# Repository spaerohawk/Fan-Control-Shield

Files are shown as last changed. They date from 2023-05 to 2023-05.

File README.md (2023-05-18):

# Fan-Control-Shield
 ## Design files for Fan Control Shield for Nucleo f4x9zi.
  
 Designed by Chris Dougherty while a graduate student at Caltech. 
 
 These design files are open-sourced pursuant to requirements set forth by NASA's Jet Propulsion Laboratory (JPL). A total of two research-grade fan array wind tunnels (FAWTs) were designed and developed to assist experimental campaign efforts to chamber-test Ingenuity (Mars Helicopter) in simulated Martian forward flight conditions. Given the multi-sourcedness of fan arrays, printed circuit breakout boards that neatly interface with multiples of fan units designed to meet electrical/thermal specifications and off-gassing chamber requirements were set forth in the scope of work.
 
- A 11x11x1 fan array was constructed in the basement of GALCIT using the Fan Control Shield found in release [v1.0.0](https://github.com/spaerohawk/Fan-Control-Shield/releases/tag/v1.0.0). 
* A 21x21x2 fan array[^1] was constructed in the 25-ft Space Simulator at JPL using the Fan Control Shield found in release [v1.1.0](https://github.com/spaerohawk/Fan-Control-Shield/releases/tag/v1.1.0).
  * Direct PDF access to the above noted paper can be found [here](https://rdcu.be/dcesM). 

[^1]: Veismann, M., Dougherty, C., Rabinovitch, J. et al. Low-density multi-fan wind tunnel design and testing for the Ingenuity Mars Helicopter. Exp Fluids 62, 193 (2021). https://doi.org/10.1007/s00348-021-03278-5

 Creative Commons Attribution/Share-Alike, all text above must be included in any redistribution. See license.txt for additional information.

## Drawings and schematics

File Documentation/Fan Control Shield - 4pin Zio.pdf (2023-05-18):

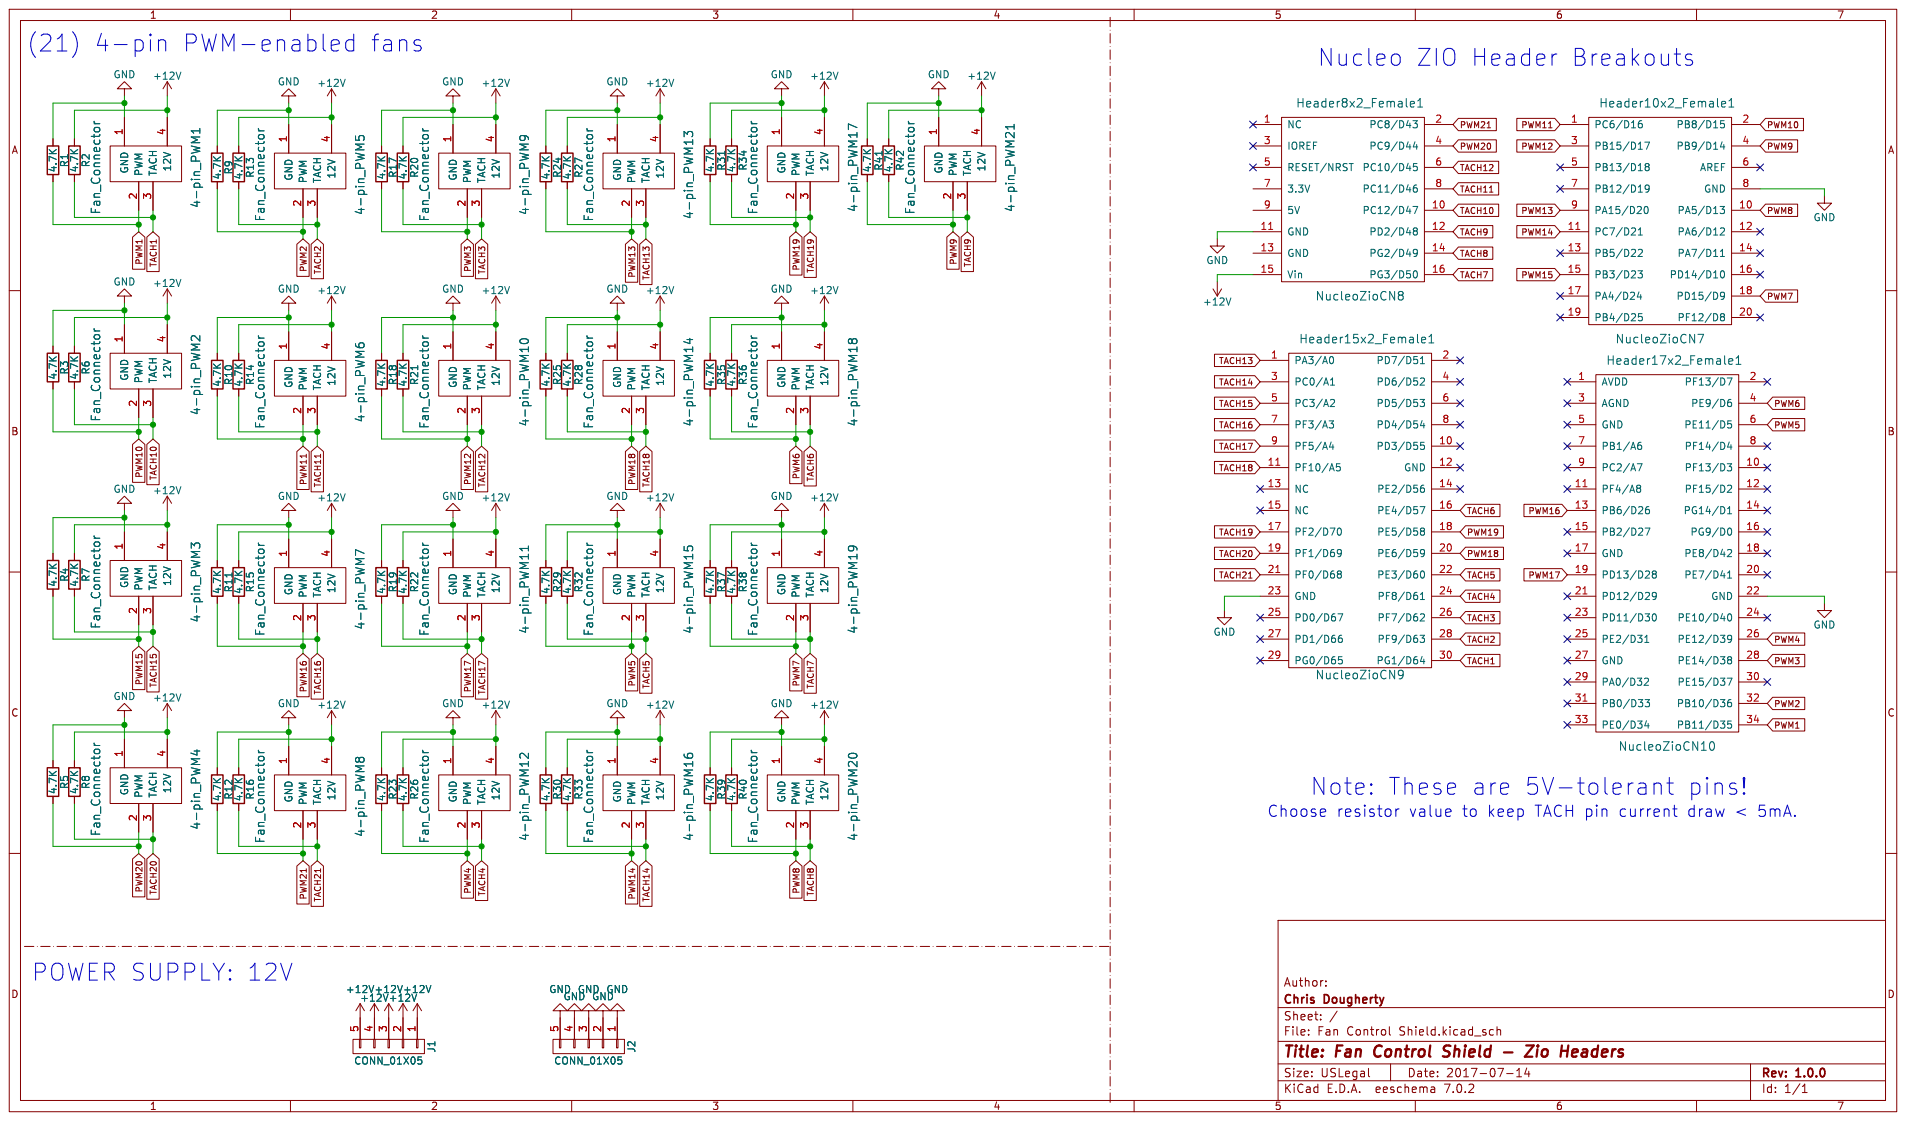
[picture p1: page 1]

Id: 1/1 Title: Fan Control Shield - Zio Headers

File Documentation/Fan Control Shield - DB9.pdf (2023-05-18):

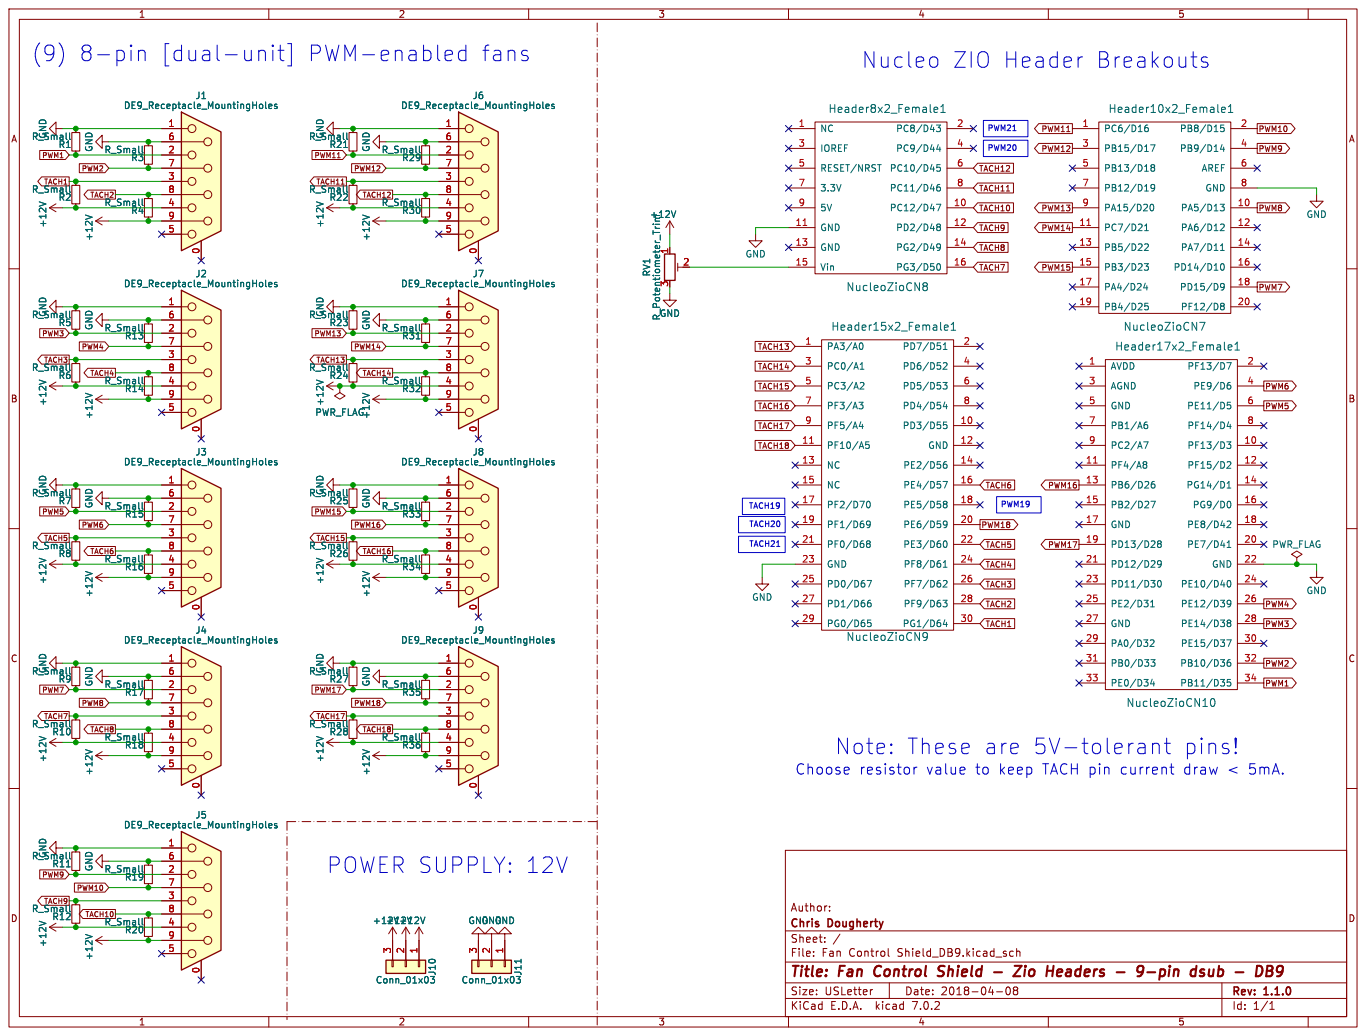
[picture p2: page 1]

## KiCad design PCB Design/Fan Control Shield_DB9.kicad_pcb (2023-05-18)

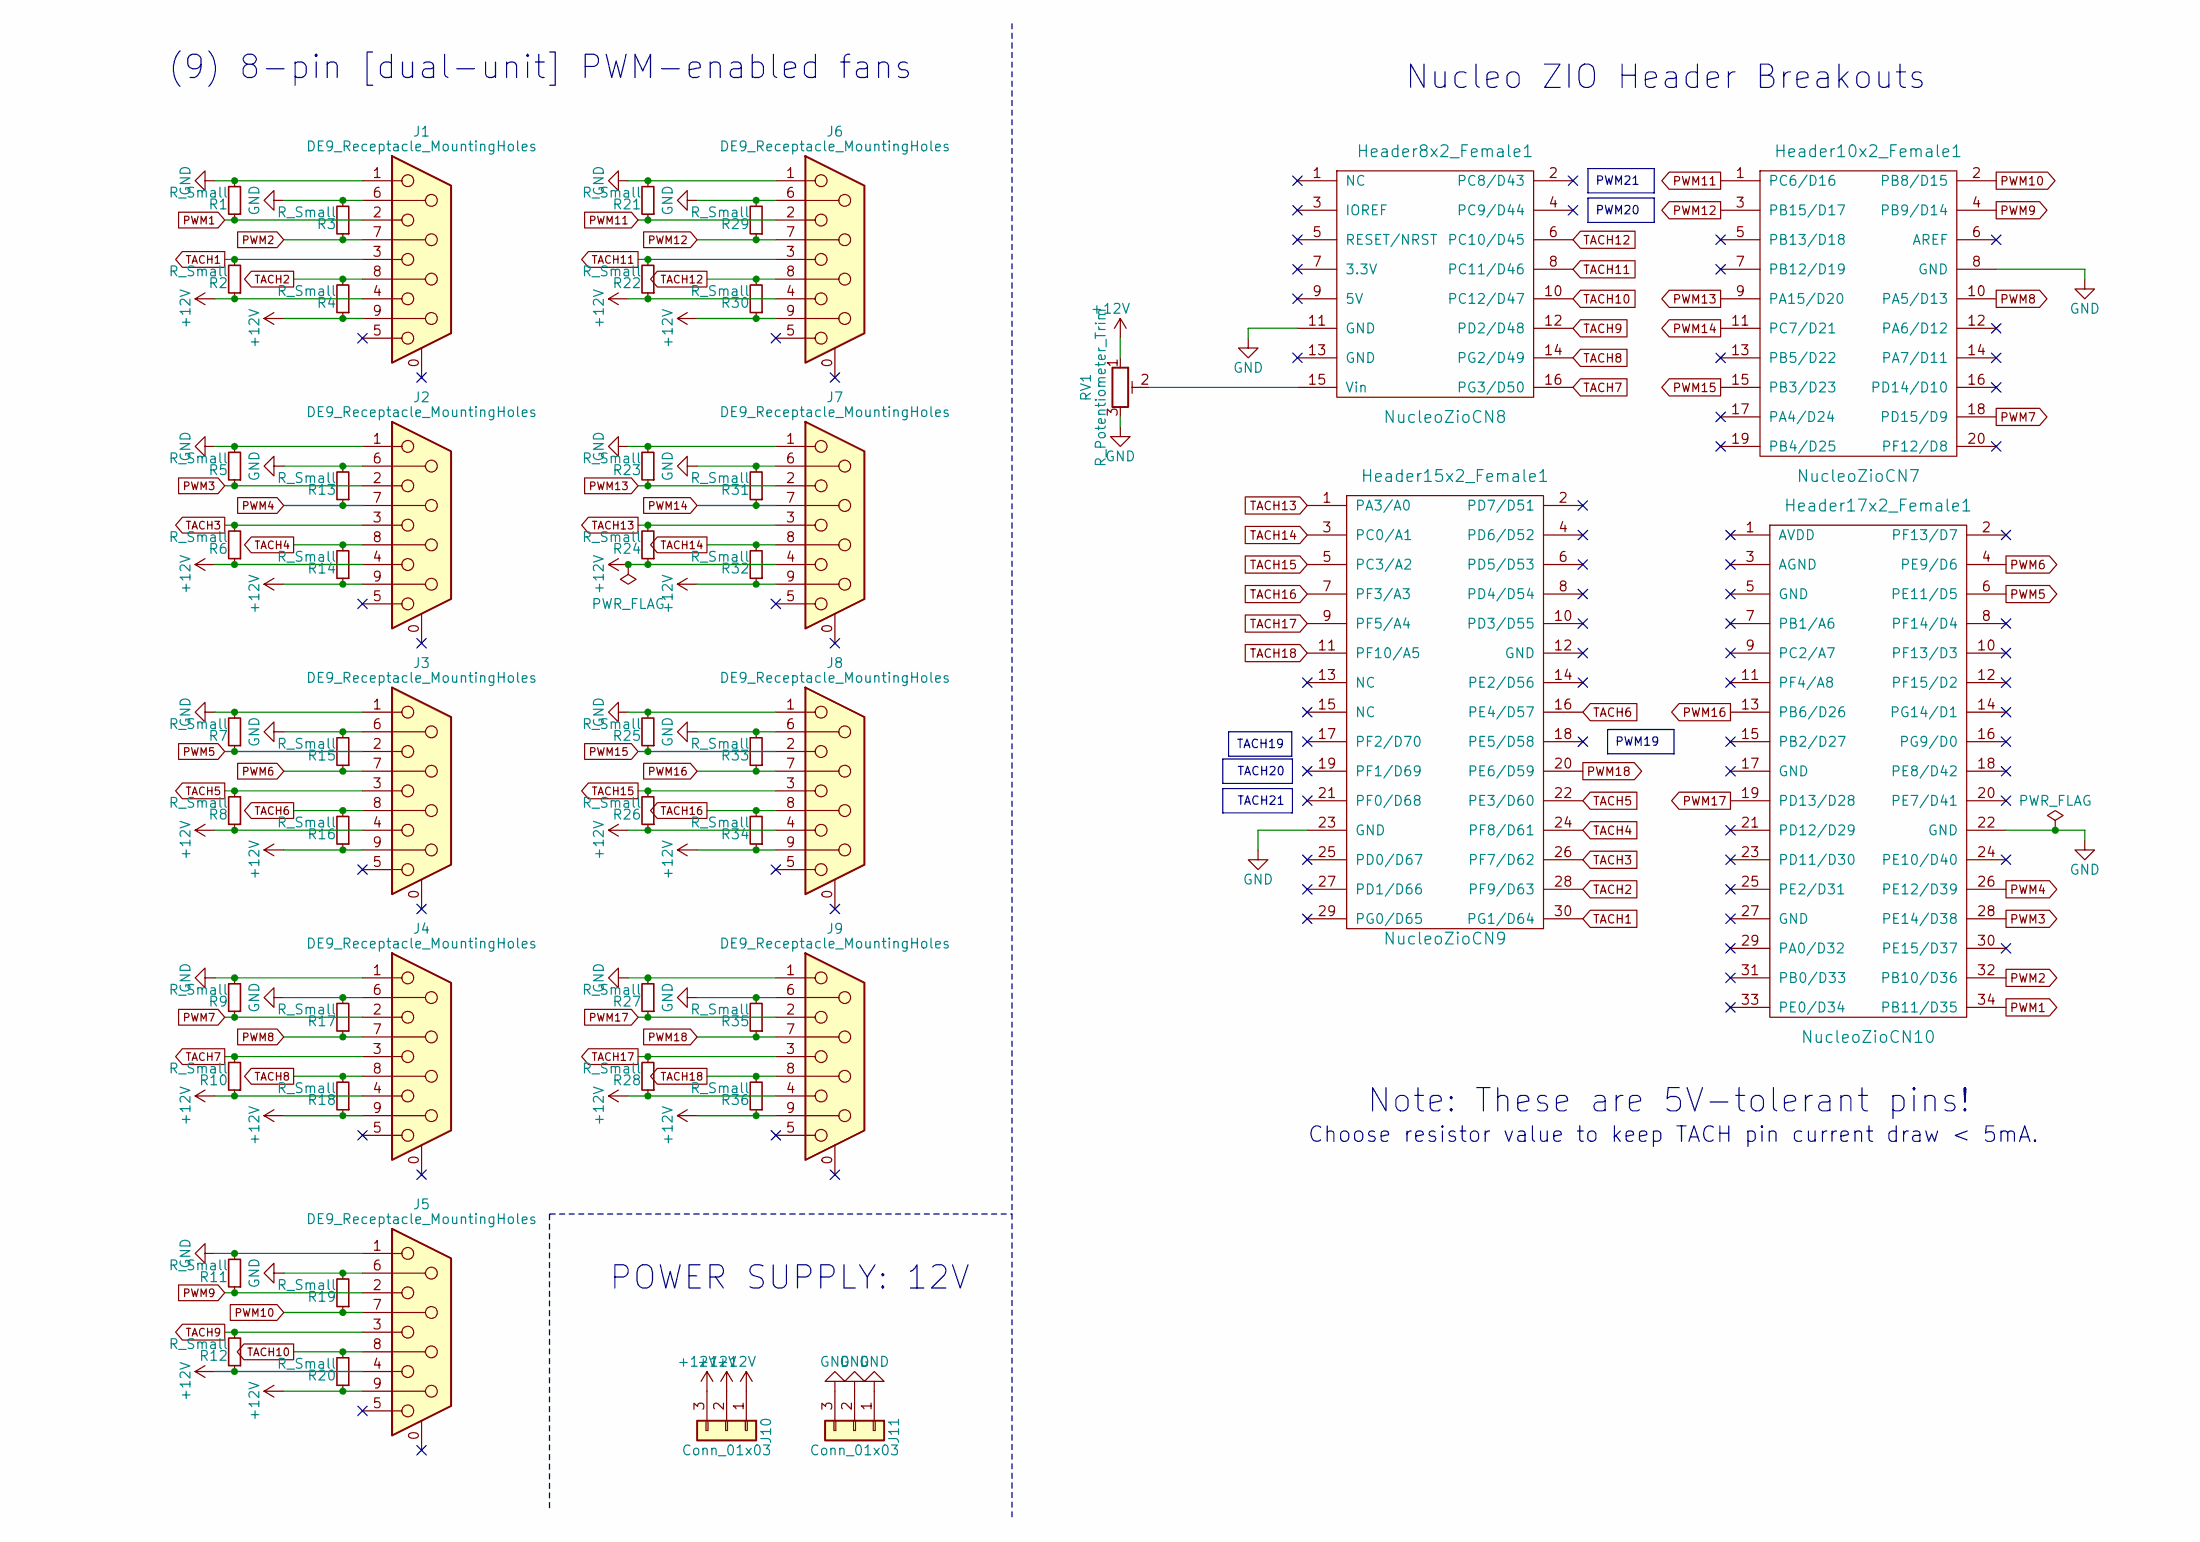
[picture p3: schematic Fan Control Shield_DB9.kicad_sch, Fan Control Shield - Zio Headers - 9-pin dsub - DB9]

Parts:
Header8x2_Female1: NucleoZioCN8; Socket_Strip_Straight_2x08_Pitch2.54mm
Header10x2_Female1: NucleoZioCN7; Socket_Strip_Straight_2x10_Pitch2.54mm
Header15x2_Female1: NucleoZioCN9; Socket_Strip_Straight_2x15_Pitch2.54mm
Header17x2_Female1: NucleoZioCN10; Socket_Strip_Straight_2x17_Pitch2.54mm
J1, J2, J3, J4, J5, J6, J7, J8, J9: DE9_Receptacle_MountingHoles; DSUB-9_Female_Vertical_P2.77x2.84mm_MountingHoles
J10, J11: Conn_01x03; CONN-TE-AMP3_P9.52
R1, R2, R3, R4, R5, R6, R7, R8, R9, R10, R11, R12, R13, R14, R15, R16, R17, R18, R19, R20, R21, R22, R23, R24, R25, R26, R27, R28, R29, R30, R31, R32, R33, R34, R35, R36: R_Small; R_1206_HandSoldering
RV1: R_Potentiometer_Trim; Potentiometer_Bourns_3266Y_Vertical

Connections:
+12V: J1.4, J1.9, J2.4, J2.9, J3.4, J3.9, J4.4, J4.9, J5.4, J5.9, J6.4, J6.9, J7.4, J7.9, J8.4, J8.9, J9.4, J9.9, J10.1, J10.2, J10.3, R2.1, R4.1, R6.1, R8.1, R10.1, R12.1, R14.1, R16.1, R18.1, R20.1, R22.1, R24.1, R26.1, R28.1, R30.1, R32.1, R34.1, R36.1, RV1.1
GND: Header8x2_Female1.11 (GND), Header10x2_Female1.8 (GND), Header15x2_Female1.23 (GND), Header17x2_Female1.22 (GND), J1.1, J1.6, J2.1, J2.6, J3.1, J3.6, J4.1, J4.6, J5.1, J5.6, J6.1, J6.6, J7.1, J7.6, J8.1, J8.6, J9.1, J9.6, J11.1, J11.2, J11.3, R1.2, R3.2, R5.2, R7.2, R9.2, R11.2, R13.2, R15.2, R17.2, R19.2, R21.2, R23.2, R25.2, R27.2, R29.2, R31.2, R33.2, R35.2, RV1.3; also elsewhere on the board
unnamed 2: Header8x2_Female1.15 (Vin), RV1.2; also elsewhere on the board
PWM1: Header17x2_Female1.34 (PB11/D35), J1.2, R1.1; also elsewhere on the board
PWM2: Header17x2_Female1.32 (PB10/D36), J1.7, R3.1; also elsewhere on the board
PWM3: Header17x2_Female1.28 (PE14/D38), J2.2, R5.1; also elsewhere on the board
PWM4: Header17x2_Female1.26 (PE12/D39), J2.7, R13.1; also elsewhere on the board
PWM5: Header17x2_Female1.6 (PE11/D5), J3.2, R7.1; also elsewhere on the board
PWM6: Header17x2_Female1.4 (PE9/D6), J3.7, R15.1; also elsewhere on the board
PWM7: Header10x2_Female1.18 (PD15/D9), J4.2, R9.1; also elsewhere on the board
PWM8: Header10x2_Female1.10 (PA5/D13), J4.7, R17.1; also elsewhere on the board
PWM9: Header10x2_Female1.4 (PB9/D14), J5.2, R11.1; also elsewhere on the board
PWM10: Header10x2_Female1.2 (PB8/D15), J5.7, R19.1; also elsewhere on the board
PWM11: Header10x2_Female1.1 (PC6/D16), J6.2, R21.1; also elsewhere on the board
PWM12: Header10x2_Female1.3 (PB15/D17), J6.7, R29.1; also elsewhere on the board
PWM13: Header10x2_Female1.9 (PA15/D20), J7.2, R23.1; also elsewhere on the board
PWM14: Header10x2_Female1.11 (PC7/D21), J7.7, R31.1; also elsewhere on the board
PWM15: Header10x2_Female1.15 (PB3/D23), J8.2, R25.1; also elsewhere on the board
PWM16: Header17x2_Female1.13 (PB6/D26), J8.7, R33.1; also elsewhere on the board
PWM17: Header17x2_Female1.19 (PD13/D28), J9.2, R27.1; also elsewhere on the board
PWM18: Header15x2_Female1.20 (PE6/D59), J9.7, R35.1; also elsewhere on the board
TACH1: Header15x2_Female1.30 (PG1/D64), J1.3, R2.2; also elsewhere on the board
TACH2: Header15x2_Female1.28 (PF9/D63), J1.8, R4.2; also elsewhere on the board
TACH3: Header15x2_Female1.26 (PF7/D62), J2.3, R6.2; also elsewhere on the board
TACH4: Header15x2_Female1.24 (PF8/D61), J2.8, R14.2; also elsewhere on the board
TACH5: Header15x2_Female1.22 (PE3/D60), J3.3, R8.2; also elsewhere on the board
TACH6: Header15x2_Female1.16 (PE4/D57), J3.8, R16.2; also elsewhere on the board
TACH7: Header8x2_Female1.16 (PG3/D50), J4.3, R10.2; also elsewhere on the board
TACH8: Header8x2_Female1.14 (PG2/D49), J4.8, R18.2; also elsewhere on the board
TACH9: Header8x2_Female1.12 (PD2/D48), J5.3, R12.2; also elsewhere on the board
TACH10: Header8x2_Female1.10 (PC12/D47), J5.8, R20.2; also elsewhere on the board
TACH11: Header8x2_Female1.8 (PC11/D46), J6.3, R22.2; also elsewhere on the board
TACH12: Header8x2_Female1.6 (PC10/D45), J6.8, R30.2; also elsewhere on the board
TACH13: Header15x2_Female1.1 (PA3/A0), J7.3, R24.2; also elsewhere on the board
TACH14: Header15x2_Female1.3 (PC0/A1), J7.8, R32.2; also elsewhere on the board
TACH15: Header15x2_Female1.5 (PC3/A2), J8.3, R26.2; also elsewhere on the board
TACH16: Header15x2_Female1.7 (PF3/A3), J8.8, R34.2; also elsewhere on the board
TACH17: Header15x2_Female1.9 (PF5/A4), J9.3, R28.2; also elsewhere on the board
TACH18: Header15x2_Female1.11 (PF10/A5), J9.8, R36.2; also elsewhere on the board

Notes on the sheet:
PWM20
PWM21
TACH19
PWM19
TACH21
TACH20
POWER SUPPLY: 12V
(9) 8-pin [dual-unit] PWM-enabled fans
Nucleo ZIO Header Breakouts
Choose resistor value to keep TACH pin current draw < 5mA.
Note: These are 5V-tolerant pins!

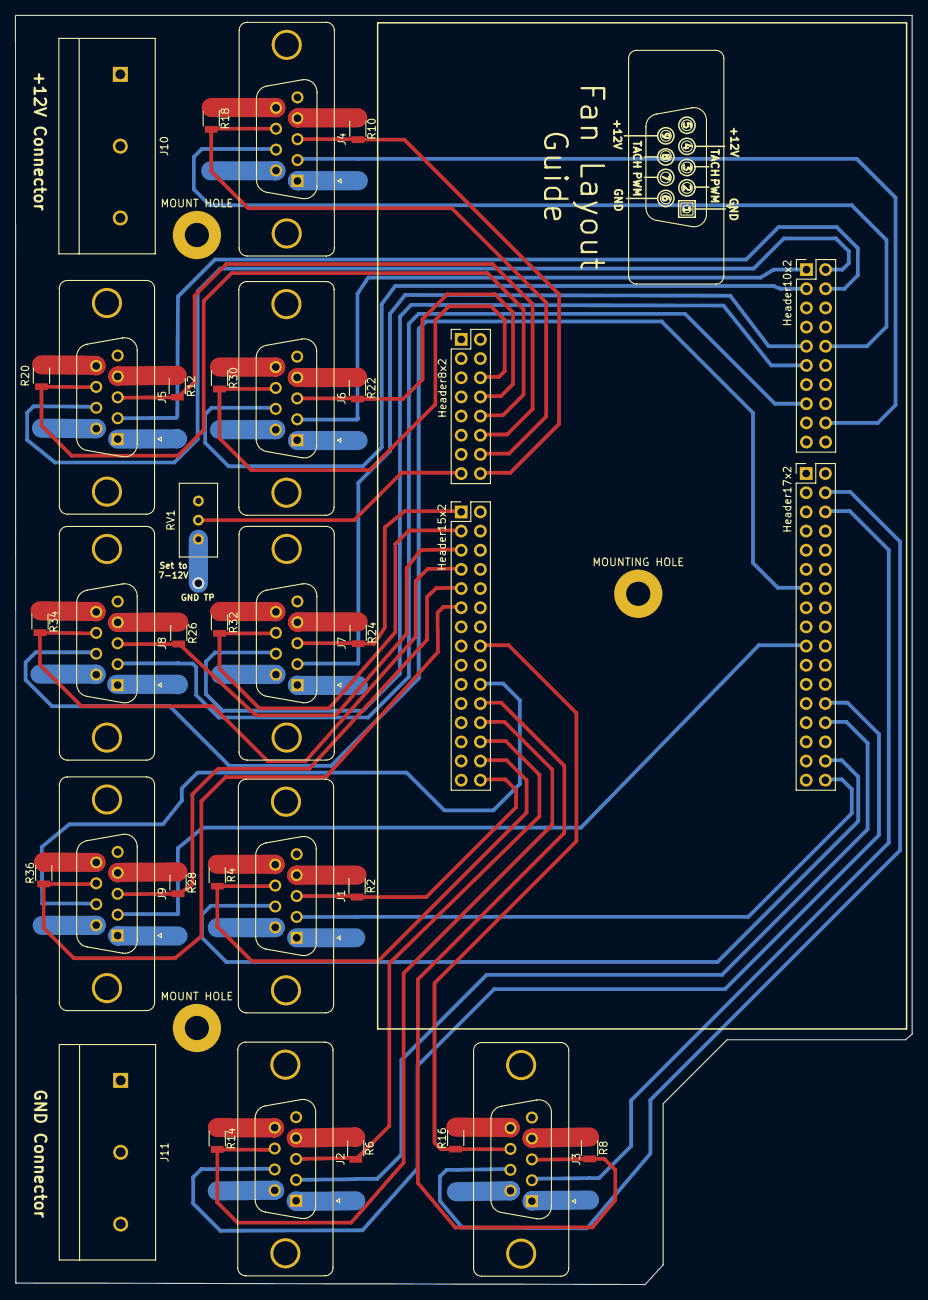
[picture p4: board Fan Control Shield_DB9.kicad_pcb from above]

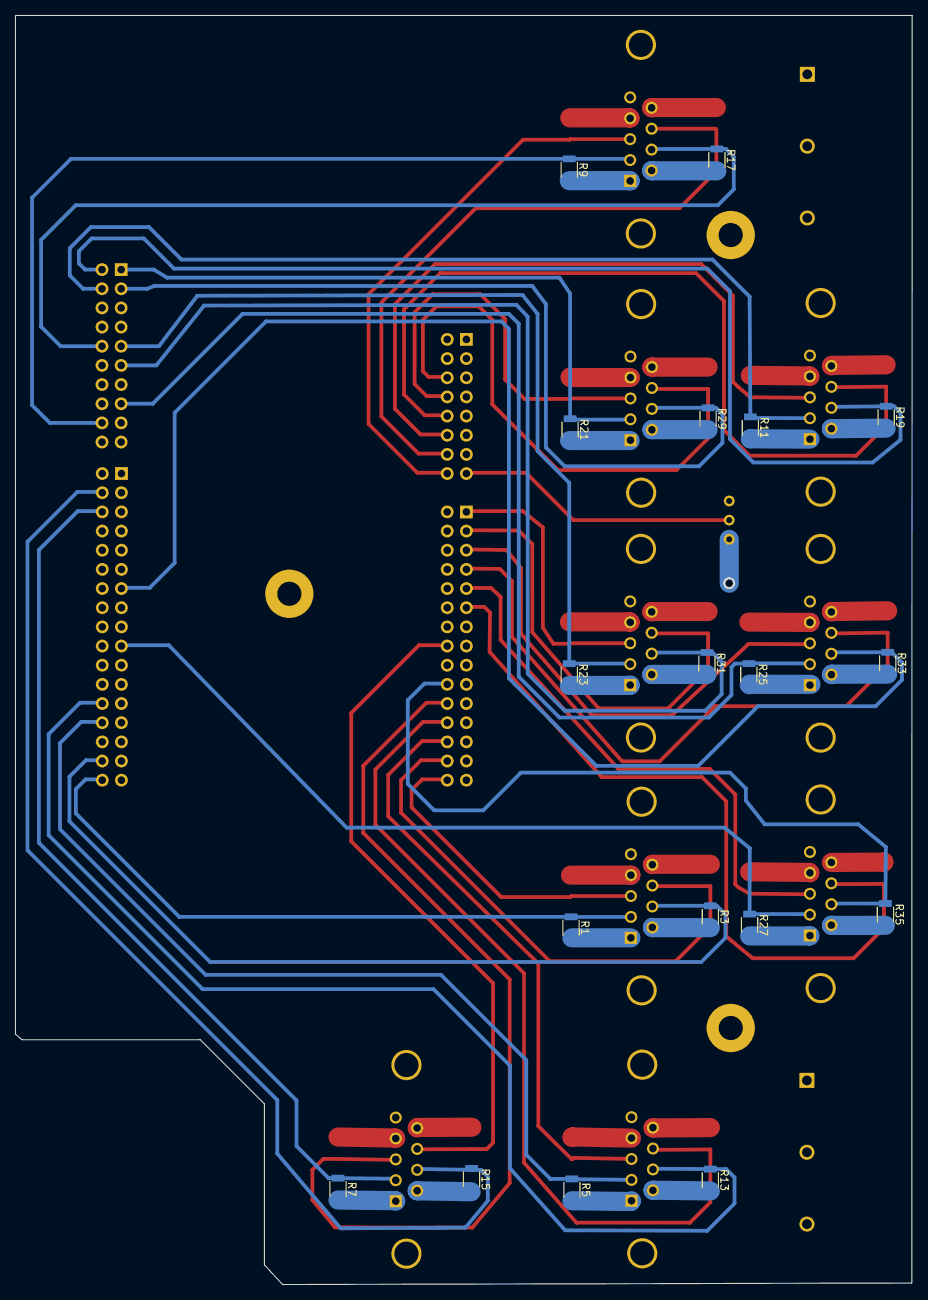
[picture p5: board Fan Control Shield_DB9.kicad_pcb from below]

Board: 4 copper layers, 118.8 x 168.2 mm, 56 parts (18 on the bottom side), 39 nets.

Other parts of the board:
Fan Layout Guide: Fan Layout Guide; Fan Layout Guide - DB9
Header8x2: NucleoZioCN8; Socket_Strip_Straight_2x08_Pitch2.54mm
Header10x2: NucleoZioCN7; Socket_Strip_Straight_2x10_Pitch2.54mm
Header15x2: NucleoZioCN9; Socket_Strip_Straight_2x15_Pitch2.54mm
Header17x2: NucleoZioCN10; Socket_Strip_Straight_2x17_Pitch2.54mm
MOUNT HOLE: MountingHole_3.2mm_M3_Pad
MOUNT HOLE#2: MountingHole_3.2mm_M3_Pad
MOUNTING HOLE: MountingHole_3.2mm_M3_Pad

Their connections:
GND: Header8x2.11 (GND), Header10x2.8 (GND), Header15x2.23 (GND), Header17x2.22 (GND); also elsewhere on the board
unnamed 2: Header8x2.15 (Vin); also elsewhere on the board
PWM1: Header17x2.34 (PB11/D35); also elsewhere on the board
PWM2: Header17x2.32 (PB10/D36); also elsewhere on the board
PWM3: Header17x2.28 (PE14/D38); also elsewhere on the board
PWM4: Header17x2.26 (PE12/D39); also elsewhere on the board
PWM5: Header17x2.6 (PE11/D5); also elsewhere on the board
PWM6: Header17x2.4 (PE9/D6); also elsewhere on the board
PWM7: Header10x2.18 (PD15/D9); also elsewhere on the board
PWM8: Header10x2.10 (PA5/D13); also elsewhere on the board
PWM9: Header10x2.4 (PB9/D14); also elsewhere on the board
PWM10: Header10x2.2 (PB8/D15); also elsewhere on the board
PWM11: Header10x2.1 (PC6/D16); also elsewhere on the board
PWM12: Header10x2.3 (PB15/D17); also elsewhere on the board
PWM13: Header10x2.9 (PA15/D20); also elsewhere on the board
PWM14: Header10x2.11 (PC7/D21); also elsewhere on the board
PWM15: Header10x2.15 (PB3/D23); also elsewhere on the board
PWM16: Header17x2.13 (PB6/D26); also elsewhere on the board
PWM17: Header17x2.19 (PD13/D28); also elsewhere on the board
PWM18: Header15x2.20 (PE6/D59); also elsewhere on the board
TACH1: Header15x2.30 (PG1/D64); also elsewhere on the board
TACH2: Header15x2.28 (PF9/D63); also elsewhere on the board
TACH3: Header15x2.26 (PF7/D62); also elsewhere on the board
TACH4: Header15x2.24 (PF8/D61); also elsewhere on the board
TACH5: Header15x2.22 (PE3/D60); also elsewhere on the board
TACH6: Header15x2.16 (PE4/D57); also elsewhere on the board
TACH7: Header8x2.16 (PG3/D50); also elsewhere on the board
TACH8: Header8x2.14 (PG2/D49); also elsewhere on the board
TACH9: Header8x2.12 (PD2/D48); also elsewhere on the board
TACH10: Header8x2.10 (PC12/D47); also elsewhere on the board
TACH11: Header8x2.8 (PC11/D46); also elsewhere on the board
TACH12: Header8x2.6 (PC10/D45); also elsewhere on the board
TACH13: Header15x2.1 (PA3/A0); also elsewhere on the board
TACH14: Header15x2.3 (PC0/A1); also elsewhere on the board
TACH15: Header15x2.5 (PC3/A2); also elsewhere on the board
TACH16: Header15x2.7 (PF3/A3); also elsewhere on the board
TACH17: Header15x2.9 (PF5/A4); also elsewhere on the board
TACH18: Header15x2.11 (PF10/A5); also elsewhere on the board

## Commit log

2023-05-15 Update .gitignore
    Include fp-lib-table.
    When project specific libraries are added in KiCAD, a fp-lib-table is generated locally.
    Will instead consider Library management with submodules.
2023-05-15 Add original design files (ported)
    Upload KiCAD source files originally created in 4.0.6 ported into 7.0.2.
    Automatic library footprint associations likely means (significant) design rule check errors.
    KiCAD moved to entirely different file naming convention and attempts to reconcile legacy files by re-saving in new format, but custom libraries do not seem to port over correctly, if at all.
    [Fan Control Shield.kicad_pcb, Fan Control Shield.kicad_sch]
2023-05-18 Delete original design files - kk254
    Moving away from antiquated original prototype (plastic 4-pin connectors do not meet current/thermal demands).
    [Fan Control Shield.kicad_pcb, Fan Control Shield.kicad_sch]
2023-05-18 Add new 9-pin dsub design files (ported)
    The fan control shield quickly evolved away from the original (21) 4-pin fan prototype shield in favor of the more robust, metallic, 5+ amp per pin current carrying capacity 9-pin dsub connectors, ab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
    [Fan Control Shield_DB9.kicad_pcb, Fan Control Shield_DB9.kicad_sch]
